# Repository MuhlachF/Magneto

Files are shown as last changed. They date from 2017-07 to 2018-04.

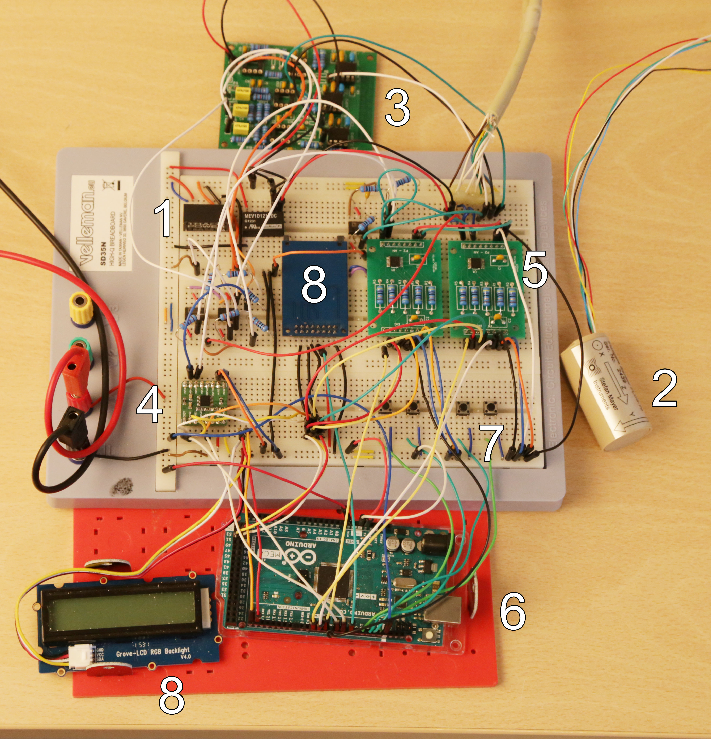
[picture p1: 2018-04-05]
Magnetometre/Prototype.jpg

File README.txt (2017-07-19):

---------------------------------
1. Principe du sondage éléctrique
---------------------------------
La prospection électrique consiste à injecter des courants sur une paire 
d’électrodes plantées dans le sol et à mesurer des potentiels en d’autres 
points de la surface. 

Livre Applied Geophysics 1: Electrical Methods
Auteur principal : Nicolas Florsch / Co-auteur : Frédéric MUHLACH
Relié: 220 pages
Editeur : ISTE Press - Elsevier (20 novembre 2017)
Langue : Anglais
ISBN-10: 1785481991
ISBN-13: 978-1785481994

-----------------------------------
2. Présentation du projet : Magneto
-----------------------------------

Le projet de réalisation qui vous est ici présenté est destiné à la prospection 
électrique du sous-sol par mesure de résistivité. Cet appareil est «opensource» 
et vous pourrez donc modifier à votre guise le programme qu’il contient pour 
l’adapter à vos besoins ou ajouter de nouvelles fonctionnalités. 

Cet appareil est uniquement dédié à l’acquisition de valeurs analogiques, 
telles qu’intensités et tensions. Les signaux sont ensuite convertis au format 
numérique et sauvegardés sur un support de stockage pour y être analysés, à
l’aide d’un logiciel spécialisé de géophysique. Il s’agit de déterminer la 
variation spatiale des résistivités du sous-sol.

-------------------------
3. Architecture du projet
-------------------------
                          |---------------|             |-------------|
                          | Affichage des |             |  Horodatage | 
                          | informations  |             |    + GPS    |
                          |---------------|             |-------------|
                                   ^                            |
                                   |                            V                
    |------------|          |------------|         |------------------------|
    | Conversion |--------->| Traitement |-------->| Sauvegarde des données |
    | Analog/Num |          |    (µc)    |         |       collectées       |
    |------------|          |------------|         |------------------------|
                                   |
                                   v
                            |------------|
                            | Saisie des |
                            | paramètres |
                            |------------|
	
----------------------------------------
4. Présentation des composants matériels
----------------------------------------
4.1 Le microcontrôleur
----------------------------------------
Le microcontrôleur est un circuit intégré (ou IC Integrated Circuit) dont les 
tâches principales sont :
	• Le traitement des informations,
	• Le pilotage des périphériques connectés sur ses broches.

Notre choix s’est porté sur la version Arduino Mega2560, qui dispose de la 
quantité de mémoire suffisante pour faire tourner le programme. 

Remarque : le modèle UNO, reste utilisable, à condition de renoncer à 
l’acquisition des données GPS.

https://www.arduino.cc/en/Main/ArduinoBoardMega2560

-----------------------------------------
4.2 Le convertisseur analogique-numérique
-----------------------------------------
Le convertisseur analogique numérique CAN (ou ADC Analog to Digital Converter) 
est un dispositif électronique qui traduit des signaux analogiques en données 
numériques.

Les entrées des CAN acceptent généralement deux modes de fonctionnement :
	• Single Ended : tension mesurée sur un seul fil, avec pour référence la 
	masse du montage. 
	• Différentiel : tension mesurée entre entre deux fils ; les interférences, 
	présentes sur les deux voies, ne sont donc pas prises en compte.
	
Le convertisseur ADS1115 (16 bits de résolution) est ici utilisé dans sa version
«breakout Board » par la société Adafruit :

https://www.adafruit.com/product/1085

-------------------------
4.3 Le Clavier analogique
-------------------------
périphérique proposé par Sparkfun (VKey PRT12080 )

https://www.sparkfun.com/products/12080

Mapping du clavier :

#############################
#        #         #        #
#   1    # 2 ou ^  #   3    #                 
#        #         #        #
#############################
#        #         #        #
#   4    # 5 ou OK #   6    #
#        #         #        #
#############################
#        #         #        #
#   7    # 8 ou v  #   9    #
#        #         #        #
#############################
# cls .  #         #        #
# ou ret #    0    #  Enter #
#        #         #        #
#############################

---------------------
4.4 Ecran LCD RVB I²C
---------------------
Ecran de 2 lignes de 16 caractères, qui affiche les informations de paramétrage 
et les menus. Un rétroéclairage peut être activé.

http://wiki.seeed.cc/Grove-LCD_RGB_Backlight/

--------------
4.5 Module RTC
--------------
L’horloge RTC (Real Time Clock) indique l'heure à la nanoseconde près. La carte 
proposée au format Grove par la société Seeed ,dont le composant central est un 
circuit DS1307.

http://wiki.seeed.cc/Grove-RTC/

--------------------------------------
4.6 Lecteur de carte µSD au format SPI
--------------------------------------
Support de stockage utilisé pour sauvegarder toutes les données au fil des 
acquisitions.

https://www.adafruit.com/product/254

-------------
5. Connexions
-------------

|------------------------------------------------------------------------------|
|       Périphérique      |   Connexion et alimentation    | Protocole utilisé |
|------------------------------------------------------------------------------|
| Clavier                 | + -> 5 Volts et GND (masse)    | Analogique        |
|                         | Out -> Entrée Arduino A0       |                   |
|------------------------------------------------------------------------------|
| Option (GPS Adafruit)   | Vin (5Volts) et GND (masse)    | Série             |
|                         | TX -> RX1 Arduino              |                   |
|                         | RX -> TX1 Arduino              |                   |
|------------------------------------------------------------------------------|
| Lecteur de carte microSD| + -> 5 Volts et GND (masse)    | SPI               |
| (Adafruit)              | CLK -> port 52 (SCK)           |                   |
|                         | DO -> port 50 (MISO)           |                   |
|                         | DI -> port 51 (MOSI)           |                   |
|                         | CS -> port 53 (SS)             |                   |
|------------------------------------------------------------------------------|
| ADS1115 (Adafruit)      | VDD -> 5 Volts et GND (masse)  |                   |
|                         | SCL -> port 21 (SCL)           | I²C               |
|                         | SDA -> port 20 (SDA)           | (Adr : 0x48)      |
|                         | ADR -> GND                     |                   |
|------------------------------------------------------------------------------|
| Module RTC (Grove) 	  | VDD -> 5 Volts et GND (masse)  | I²C               |
|                         | SCL -> port 21 (SCL)           |                   |
|                         | SDA -> port 20 (SDA)           |                   |
|------------------------------------------------------------------------------|
| Ecran LCD (Grove) 	  | VDD -> 5 Volts et GND (masse)  | I²C               |
|                         | SCL -> port 21 (SCL)           |                   |
|                         | SDA -> port 20 (SDA)           |                   |
|------------------------------------------------------------------------------|

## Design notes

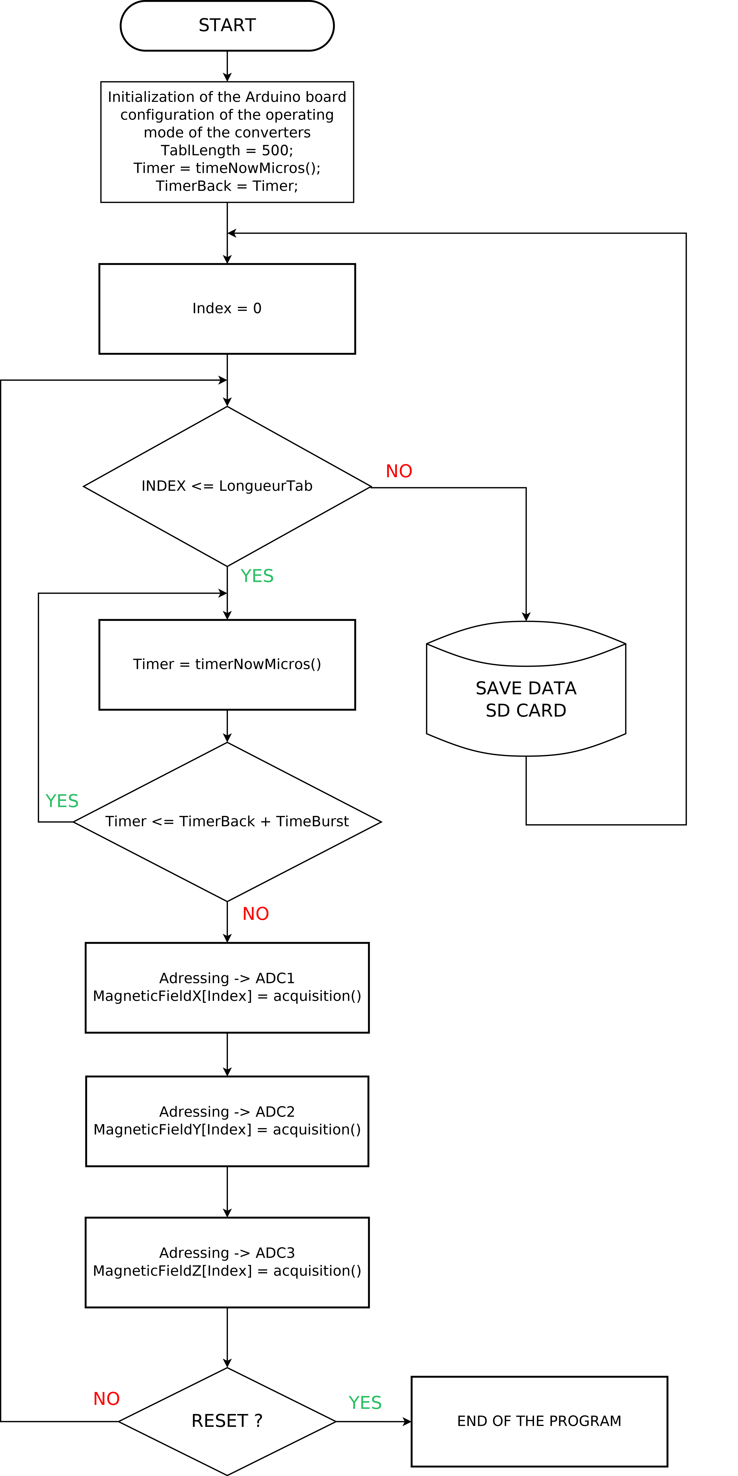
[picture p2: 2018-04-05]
Magnetometre/Principe_Magneto/11_Algo.png

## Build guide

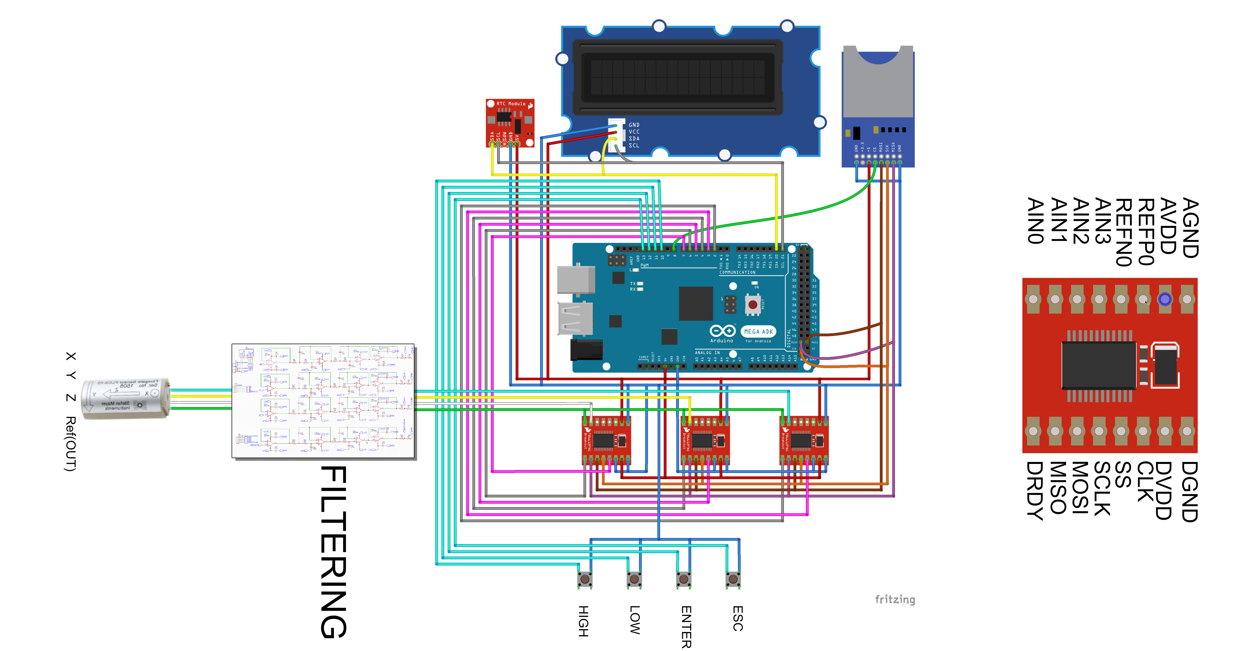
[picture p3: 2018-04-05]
Magnetometre/Assemblage_modules.png

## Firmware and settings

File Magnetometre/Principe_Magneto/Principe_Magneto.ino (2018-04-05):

/*************************************************************
Protocentral_ADS1220.ino
Exemple d'utilisation de la nouvelle librairie
Author : Frédéric MUHLACH
|ads1220 pin label| Pin Function         |Arduino Connection UNO| MEGA |
|-----------------|:--------------------:|---------------------:|:-----
| DRDY            | Data ready Output pin|  D6                  | D6           
| MISO            | Slave Out            |  D12                 | D50
| MOSI            | Slave In             |  D11                 | D51
| SCLK            | Serial Clock         |  D13                 | D52 
| CS              | Chip Select          |  D7                  | D7
| DVDD            | Digital VDD          |  +5V                 |
| DGND            | Digital Gnd          |  Gnd                 |
| AN0-AN3         | Analog Input         |  Analog Input        |
| AVDD            | Analog VDD           |  -                   |
| AGND            | Analog Gnd           |  -                   |
****************************************************************************/
/* Configuration du CAN 
 * Pour les entrées en mode différentiel
 * Commande :  * ADS1220.set_mode(INPUT_SINGLE_ENDED_AIN0);
 * Paramètres : INPUT_DIFF_AIN0_AIN1 
                INPUT_DIFF_AIN0_AIN2
                INPUT_DIFF_AIN0_AIN3
                INPUT_DIFF_AIN1_AIN2
                INPUT_DIFF_AIN1_AIN3
                INPUT_DIFF_AIN2_AIN3
                INPUT_DIFF_AIN1_AIN0
                INPUT_DIFF_AIN3_AIN2

 * Pour les entrées en mode Single Ended
                INPUT_SINGLE_ENDED_AIN0
                INPUT_SINGLE_ENDED_AIN1
                INPUT_SINGLE_ENDED_AIN2
                INPUT_SINGLE_ENDED_AIN3

 * Vitesse de sampling pour le mode NORMAL  : 20, 45, 90, 175, 330, 600 et 1000 SPS
 * Vitesse de sampling pour le mode TURBO   : 40, 90, 180, 350, 660, 1200 et 2000 SPS
 * 
 * Pour la mise en place d'un filtrage numérique (uniquement pour 20SPS)
 * Commande :   ADS1220.set_filter(REJECTION_50_60HZ)
 * Paramètres : NOFILTER
 *              REJECTION_50_60HZ
 *              REJECTION_50HZ
 *              REJECTION_60HZ
 
 * Pour le mode de fonctionnement du convertisseur
 * Commande :   ADS1220.set_operating_mode(NORMAL)
 * Paramètres : NORMAL
 *              DUTY_CYCLE
 *              TURBO

*/

/* Versionning :
 *  0.1 : Intégration de la librairie ADS1220 et tests de fonctionnement
 *  0.2 : Passage sur Arduino MEGA 2560
 *  0.3 : Intégration d'un menu simplifié
 *    1.  Start scan
      2.  Output data
      3.  Set parameters
          a.  Grid size (max 50*50m) ?
          b.  Interval (increment 0.2m avec max interval = 1m)
          c.  SPS (Samples Per Second)
          d.  Sensors (mono composante ou 3D)
          e.  Reject (activation du filtre rejecteur 50 ou 60Hz)
          f.  Space sensors (distance entre les deux capteurs mono composante)
          g.  Save config
          h.  System reset
      4.  Calibrate
 *  0.4 : Prise en compte du mode TURBO 
 *  0.5 : passage à 660SPS par convertisseur pour diminuer les temps de multiplexage entre CAN
 *  0.6 : Ajout du supersampling pour l'acquisition des signaux
 *  0.7 : Prise en compte des erreurs Offset et Gain sur les 3 entrées
 *  0.8 : Ajout du lecteur de carte SD / initialisation    
 *  0.9 : Prise en compte de l'interface de navigation
 *  0.10 : Conversion parallèle avec 2 CAN / synchronisation des CAN 
 *  0.11 : refactoring de code -> Optimisation de la fonction d'acquisition 
 *  0.12 : Vitesse de commutation fixée à 0
 *  0.13 : Ouverture de fichier
 *  0.14 : Mise en place d'un timer pour la synchronisation des conversions
 *  0.15 : intégration d'une reinit synchro SPI dans la librairie
 *  
 */

#include "Protocentral_ADS1220.h"
#include "rgb_lcd.h"
#include <SD.h>

// DESCRIPTEUR DE FICHIER
File myFile;

// IDENTIFIANTS DES CONVERTISSEURS
#define CAN1                  1
#define CAN2                  2
#define CAN3                  3

// CHIP SELECT BUS SPI
#define SDCARD_CS_PIN         8
#define ADS1220_1_CS_PIN      7
#define ADS1220_1_DRDY_PIN    6
#define ADS1220_2_CS_PIN      5
#define ADS1220_2_DRDY_PIN    4
#define ADS1220_3_CS_PIN      3
#define ADS1220_3_DRDY_PIN    2

// VITESSE DE COMMUTATION Bonne valeur -> TIME_BURST 4000, SS=8 -> 22Hz 1200SPS bruit de 3nT
//                                      -> TIME_BURST 6000, SS=1 -> 70Hz 350SPS bruit de 3nT
//                                     -> TIME_BURST 12000, SS=1 -> 55Hz 180SPS bruit de 2nT
//                                     -> TIME BURST 24000, SS=1 -> 40Hz 90SPS bruit de 1nT
//                                     -> TIME BURST 25000, SS=1 ->      
// MARCHE OK TIME_BURST 15000 et 180SPS 4SS environ 25Hz
#define TIME_BURST           50000  //en µs Baisser cette valeur augmente les erreurs de conversion ! 
                                   // La valeur est à adapter avec le nombre de SPS
#define TIME_SYNCHRO         0
#define TIME_SPI             200     // 

// SUPERSAMPLING 
#define SAMPLES               1 // 20 -> 12Hz, 15 -> 16Hz

// TAILLE TABLEAU
#define LENGTH_ACQUISITION    500  // Avec TIME_BURST=2000, SAMPLES=20, LENGTH_ACQUISITION=400 => MAX 10s de SAMPLES sans interruption

// Interface de navigation
#define KEYBOARD_F            150
#define BTN_DOWN              10
#define BTN_UP                11
#define BTN_ENTER             12
#define BTN_ESCAPE            13
#define ITEMS_MENU_PRINCIPAL  4
#define ITEMS_MENU_SECONDAIRE 8

// Capteur Magnetique 3D
#define X_SENSOR 1
#define Y_SENSOR 2
#define Z_SENSOR 3
#define SENSOR_3D_SENS_X 35 
#define SENSOR_3D_OFFSET_X 0      // sensibilité du capteur magnétique 1V = 70µT
//#define SENSOR_3D_OFFSET_X -69.923  // Offset du capteur magnétique (tension positive sur -70 à 70µT) -> 0 à 2V 

#define SENSOR_3D_SENS_Y 35     // sensibilité du capteur magnétique 1V = 70µT
#define SENSOR_3D_OFFSET_Y 0
//#define SENSOR_3D_OFFSET_Y -69.75  // Offset du capteur magnétique (tension positive sur -70 à 70µT) -> 0 à 2V 

#define SENSOR_3D_SENS_Z 35     // sensibilité du capteur magnétique 1V = 70µT
#define SENSOR_3D_OFFSET_Z 0
//#define SENSOR_3D_OFFSET_Z -69.66  // Offset du capteur magnétique (tension positive sur -70 à 70µT) -> 0 à 2V 

#define DIGIT_PRECISION 3    // Précision de l'affichage au nT    


int codeTouche;
long int timer = millis();
long int timerBack = timer;
int navigationMenuPrincipal = 0;


// Déclaration ECRAN LCD
rgb_lcd lcd;
#define colorR 0
#define colorG 0
#define colorB 0

#include <SPI.h>
#define PGA 1                 // Programmable Gain = 1
#define VREF 2.048            // Internal reference of 2.048V
#define VFSR VREF/PGA             
#define FSR (((long int)1<<23)-1)  

// Variables dédiées au convertisseur
volatile byte MSB;
volatile byte data;
volatile byte LSB;
volatile byte *SPI_RX_Buff_Ptr;

String outPutData="";

float magneticField; 
float magneticFieldX; 
float magneticFieldY; 
float magneticFieldZ; 

float magneticFieldBackX; 
float magneticFieldBackY; 
float magneticFieldBackZ; 

float MagneticFieldX = 0.0;
float MagneticFieldY = 0.0;
float MagneticFieldZ = 0.0;
float moyenne;

//long timerTab[LENGTH_ACQUISITION]={NULL};
float magneticFieldXTab[LENGTH_ACQUISITION]={NULL};
float magneticFieldYTab[LENGTH_ACQUISITION]={NULL};
float magneticFieldZTab[LENGTH_ACQUISITION]={NULL};

float sensorOffset = 0.0;
float sensorGain = 0.0;
 
Protocentral_ADS1220 ADS1220;
Protocentral_ADS1220 ADS1220_2;
Protocentral_ADS1220 ADS1220_3;

void setup()
{
  Serial.begin(250000);

  // Paramtrage de l'écran LCD 2 lignes de 16 caractères
  lcd.begin(16, 2);
  lcd.setRGB(colorR, colorG, colorB);
  
  // Initialisation du lecteur de carte SD
  pinMode(SDCARD_CS_PIN, OUTPUT);
  pinMode(SS, OUTPUT);
  activation_SD_CARD();
 
  if (!SD.begin(SDCARD_CS_PIN)) 
  {
    lcd.print("SD Problem"); 
    delay (500);
     
  }
  else
  {
    lcd.print("SD initialized.");
    delay (100);    
  }

  myFile = SD.open("DATA.txt", FILE_WRITE);
  if (myFile)
  {
    myFile.print("LANCEMENT DES ACQUISITIONS");
    myFile.println("");
    myFile.print("-----------------------------");
    myFile.println("");
    myFile.println("");
    
    myFile.close();
  }

  // Configuration interface
  pinMode (BTN_DOWN,INPUT_PULLUP);
  pinMode (BTN_UP,INPUT_PULLUP);
  pinMode (BTN_ENTER,INPUT_PULLUP);
  pinMode (BTN_ESCAPE,INPUT_PULLUP);
  
  // Initialisation des CAN ADS1220
  pinMode(ADS1220_1_CS_PIN, OUTPUT);  
  pinMode(ADS1220_1_DRDY_PIN, INPUT);  
  pinMode(ADS1220_2_CS_PIN, OUTPUT);  
  pinMode(ADS1220_2_DRDY_PIN, INPUT);
  pinMode(ADS1220_3_CS_PIN, OUTPUT);  
  pinMode(ADS1220_3_DRDY_PIN, INPUT);

  

  
  activation_ADS1220_1();
  ADS1220.set_CS_Pin(ADS1220_1_CS_PIN);
  ADS1220.set_DRDY_Pin(ADS1220_1_DRDY_PIN);
  ADS1220.begin();
  delayMicroseconds(TIME_SPI);
  ADS1220.set_mode(INPUT_DIFF_AIN1_AIN2);
  ADS1220.set_operating_mode(TURBO);
  ADS1220.set_data_rate(DR_180SPS);
  ADS1220.Continuous_conversion_mode_ON();
  ADS1220.set_filter(NOFILTER);
  ADS1220.PGA_ON(); 
  ADS1220.set_pga_gain(PGA_GAIN_4);
  delayMicroseconds(TIME_SPI);
  

  activation_ADS1220_2();
  ADS1220_2.set_CS_Pin(ADS1220_2_CS_PIN);
  ADS1220_2.set_DRDY_Pin(ADS1220_2_DRDY_PIN);
  delayMicroseconds(TIME_SPI);
  ADS1220_2.begin();
  ADS1220_2.set_mode(INPUT_DIFF_AIN0_AIN1);
  ADS1220_2.set_operating_mode(TURBO);
  ADS1220_2.set_data_rate(DR_180SPS);
  ADS1220_2.Continuous_conversion_mode_ON();
  ADS1220_2.set_filter(NOFILTER);
  ADS1220_2.PGA_ON(); 
  ADS1220_2.set_pga_gain(PGA_GAIN_4);
  delayMicroseconds(TIME_SPI);

  activation_ADS1220_3();
  ADS1220_3.set_CS_Pin(ADS1220_3_CS_PIN);
  ADS1220_3.set_DRDY_Pin(ADS1220_3_DRDY_PIN);
  delayMicroseconds(TIME_SPI);
  ADS1220_3.begin();
  ADS1220_3.set_mode(INPUT_DIFF_AIN0_AIN2);
  ADS1220_3.set_operating_mode(TURBO);
  ADS1220_3.set_data_rate(DR_180SPS);
  ADS1220_3.Continuous_conversion_mode_ON();
  ADS1220_3.set_filter(NOFILTER);
  ADS1220_3.PGA_ON(); 
  ADS1220_3.set_pga_gain(PGA_GAIN_4);
  delayMicroseconds(TIME_SPI);

  desactivation_SPI();
  affichageMenuPrincipal();     
}
 
void loop()
{
 codeTouche = testTouche();

 switch (codeTouche)
 {
   case BTN_DOWN: 
   navigationMenuPrincipal++;
   navigationMenuPrincipal=constrain(navigationMenuPrincipal,0,ITEMS_MENU_PRINCIPAL-1);
   affichageMenuPrincipal();
   break;

   case BTN_UP:
   navigationMenuPrincipal--;
   navigationMenuPrincipal=constrain(navigationMenuPrincipal,0,ITEMS_MENU_PRINCIPAL-1);
   affichageMenuPrincipal();
   break;

   case BTN_ENTER:

   switch(navigationMenuPrincipal)
   {
      case 0: 
      do
      {
        acquisition();         
      }while (digitalRead(BTN_ESCAPE));
      break;
   }
   
   break;

   case BTN_ESCAPE:
   affichageMenuPrincipal();
   break;

   default:
   break;
 } 

}

void acquisition()
{ 
  

  for (int index=0;index<LENGTH_ACQUISITION;index++)
  {
    MagneticFieldX = 0.0;
    MagneticFieldY = 0.0;
    MagneticFieldZ = 0.0;
    timer = micros();
    timerBack = timer;
    /*
    for (int i=0 ; i<SAMPLES ; i++)
    {
      */
      while (timer < (timerBack + TIME_BURST))
      {
        timer = micros();
      }
      timerBack = timer;
      //delayMicroseconds(TIME_SPI);
      magneticFieldX = Conversion_Analogique_Numerique_ADS1220(X_SENSOR,CAN1);    
      MagneticFieldX = MagneticFieldX + magneticFieldX;
      delayMicroseconds(TIME_SPI);
      
      magneticFieldY = Conversion_Analogique_Numerique_ADS1220(Y_SENSOR,CAN2);
      MagneticFieldY = MagneticFieldY + magneticFieldY;      
      delayMicroseconds(TIME_SPI);
  
      magneticFieldZ = Conversion_Analogique_Numerique_ADS1220(Z_SENSOR,CAN3);
      MagneticFieldZ = MagneticFieldZ + magneticFieldZ;
      delayMicroseconds(TIME_SPI);
/*
    }
    /*
    MagneticFieldX = MagneticFieldX / SAMPLES;
    MagneticFieldY = MagneticFieldY / SAMPLES;
    MagneticFieldZ = MagneticFieldZ / SAMPLES;
    */
    
    
    
    
   magneticField = sqrt(MagneticFieldX*MagneticFieldX+MagneticFieldY*MagneticFieldY+MagneticFieldZ*MagneticFieldZ);
   //timerTab[index] = millis(); 
   Serial.print (millis());
    Serial.print("\t");
    Serial.print(MagneticFieldX,5);
    Serial.print("\t");
    
    Serial.print(MagneticFieldY,5);
    Serial.print("\t");

    Serial.print(MagneticFieldZ,5);
    Serial.print("\t");
    Serial.print(magneticField,5);
    Serial.print("\n");
   magneticFieldXTab[index]=magneticFieldX;
   magneticFieldYTab[index]=magneticFieldY;
   magneticFieldZTab[index]=magneticFieldZ;
     
  AffichageLCD(index);    
  }
  // Activation du lecteur de carte pour enregistrement des mesures
  
  activation_SD_CARD();
  
   myFile = SD.open("DATA.txt", FILE_WRITE);
   if (myFile)
   {
 
      for (int index=0 ; index<LENGTH_ACQUISITION ; index++)
    {
      //myFile.print(timerTab[index]);
      //myFile.print(";");
      myFile.print(magneticFieldXTab[index],6);
      myFile.print(";");
      myFile.print(magneticFieldYTab[index],6);
      myFile.print(";");
      myFile.print(magneticFieldZTab[index],6);
      myFile.println("");
    }
    myFile.close();
    /*
    Serial.print("sauvegarde effectuee");
    Serial.print("\n");  
    */
  }
  
  activation_ADS1220_1();
  ADS1220.SynchroRestart();
  Conversion_Analogique_Numerique_ADS1220(X_SENSOR,CAN1);
  Conversion_Analogique_Numerique_ADS1220(X_SENSOR,CAN2);
  Conversion_Analogique_Numerique_ADS1220(X_SENSOR,CAN3);
  delayMicroseconds(TIME_SYNCHRO);

}
float Conversion_Analogique_Numerique_ADS1220(int Sensor_Canal, int Convertisseur)
{
  // Rappel des configurations / Canal
  switch (Sensor_Canal)
  {
   case X_SENSOR : 
     sensorOffset = SENSOR_3D_OFFSET_X;
     sensorGain = SENSOR_3D_SENS_X;
     break;

   case Y_SENSOR : 
     sensorOffset = SENSOR_3D_OFFSET_Y;
     sensorGain = SENSOR_3D_SENS_Y;
     break;

   case Z_SENSOR : 
     sensorOffset = SENSOR_3D_OFFSET_Z;
     sensorGain = SENSOR_3D_SENS_Z;
     break;
  }
  long int bit32;
  long int bit24;
  byte *config_reg;
  bool lock = false;

  switch (Convertisseur)
  {
    case CAN1 : 
      activation_ADS1220_1();
      SPI_RX_Buff_Ptr = ADS1220.Read_Data();
      SPI_RX_Buff_Ptr = ADS1220.Read_Data();
      if(ADS1220.NewDataAvailable = true)
      {
        ADS1220.NewDataAvailable = false;
        lock = true;
      }
      desactivation_SPI();
      break;

    case CAN2 : 
      activation_ADS1220_2();
      SPI_RX_Buff_Ptr = ADS1220_2.Read_Data();
      SPI_RX_Buff_Ptr = ADS1220_2.Read_Data();
      if(ADS1220_2.NewDataAvailable = true)
      {
        ADS1220_2.NewDataAvailable = false;
        lock = true;
      }
      desactivation_SPI();
      break;

    case CAN3 : 
      activation_ADS1220_3();
      SPI_RX_Buff_Ptr = ADS1220_3.Read_Data();
      SPI_RX_Buff_Ptr = ADS1220_3.Read_Data();
      if(ADS1220_3.NewDataAvailable = true)
      {
        ADS1220_3.NewDataAvailable = false;
        lock = true;
      }
     desactivation_SPI();
      break;
  }
  
  
  if(lock)
  {
  lock = false;
  MSB = SPI_RX_Buff_Ptr[0];    
  data = SPI_RX_Buff_Ptr[1];
  LSB = SPI_RX_Buff_Ptr[2];

  bit24 = MSB;
  bit24 = (bit24 << 8) | data;
  bit24 = (bit24 << 8) | LSB;                   // Converting 3 bytes to a 24 bit int
    
  bit24= ( bit24 << 8 );
  bit32 = ( bit24 >> 8 );                      // Converting 24 bit two's complement to 32 bit two's complement
  
  return (float)(((((bit32*VFSR)/FSR)*sensorGain))+sensorOffset);     //In  µT
  //return (float)((bit32*VFSR*1000)/FSR);     //In  mV
  } 
}


void AffichageLCD(int index)
{
  lcd.clear();
  lcd.print(index);
  lcd.setCursor(2,0);
  lcd.print("MAG1="+String(magneticField,DIGIT_PRECISION)+" "); 
}

void affichageMenuPrincipal()
{
  desactivation_SPI();
  lcd.clear();
  lcd.setCursor(0,0);
  lcd.print ("---MAIN MENU----");
  lcd.setCursor(0,1);
   switch (navigationMenuPrincipal)
 {
    case 0:
    lcd.print("1-> START");
    break;

    case 1:
    lcd.print("2-> OUTPUT DATA");
    break;

    case 2:
    lcd.print("3-> SET PARAM"); 
    break;

    case 3:
    lcd.print("4-> CALIBRATE"); 
    break;
 }
}
/* 
 *  FONCTION TEST TOUCHE
 *  RENVOI LA VALEUR DE LA TOUCHE APPUYEE
 *  AUCUN PARAMETRE
 */
int testTouche()
{  
  timer = millis();
  if ((timer - timerBack) > KEYBOARD_F)
  {   
      if (!digitalRead(BTN_DOWN))
      { 
        timerBack = timer;
        return BTN_DOWN;
      }

      if (!digitalRead(BTN_UP))
      { 
        timerBack = timer;
        return BTN_UP;
      }
      
      if (!digitalRead(BTN_ENTER))
      { 
        timerBack = timer;
        return BTN_ENTER;
      }

      if (!digitalRead(BTN_ESCAPE))
      { 
        timerBack = timer;
        return BTN_ESCAPE;
      }    
      timerBack=timer;
      
  }
    return 0;  
}

void activation_SD_CARD()
{
  digitalWrite(ADS1220_1_CS_PIN,HIGH);
  digitalWrite(ADS1220_2_CS_PIN,HIGH);
  digitalWrite(ADS1220_3_CS_PIN,HIGH);
  delayMicroseconds(TIME_SPI);
  digitalWrite(SDCARD_CS_PIN,LOW); 
  delayMicroseconds(TIME_SPI);
}

void activation_ADS1220_1()
{
  digitalWrite(SDCARD_CS_PIN,HIGH);
  digitalWrite(ADS1220_2_CS_PIN,HIGH); 
  digitalWrite(ADS1220_3_CS_PIN,HIGH); 
  delayMicroseconds(TIME_SPI);
  digitalWrite(ADS1220_1_CS_PIN,LOW);
  delayMicroseconds(TIME_SPI);
}

void activation_ADS1220_2()
{
  digitalWrite(SDCARD_CS_PIN,HIGH);
  digitalWrite(ADS1220_1_CS_PIN,HIGH); 
  digitalWrite(ADS1220_3_CS_PIN,HIGH); 
  delayMicroseconds(TIME_SPI);
  digitalWrite(ADS1220_2_CS_PIN,LOW);
  delayMicroseconds(TIME_SPI);
}

void activation_ADS1220_3()
{
  digitalWrite(SDCARD_CS_PIN,HIGH);
  digitalWrite(ADS1220_1_CS_PIN,HIGH); 
  digitalWrite(ADS1220_2_CS_PIN,HIGH); 
  delayMicroseconds(TIME_SPI);
  digitalWrite(ADS1220_3_CS_PIN,LOW);
  delayMicroseconds(TIME_SPI);
}

void desactivation_SPI()
{
  digitalWrite(SDCARD_CS_PIN,HIGH);
  digitalWrite(ADS1220_1_CS_PIN,HIGH); 
  digitalWrite(ADS1220_2_CS_PIN,HIGH); 
  digitalWrite(ADS1220_3_CS_PIN,HIGH); 
  delayMicroseconds(TIME_SPI);
}
/* 
 *  FIN FONCTION TEST TOUCHE
 */


 
 

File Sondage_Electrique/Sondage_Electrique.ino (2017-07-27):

/*
  Centrale d'acquisition des mesures / magnétomètre
  

  Author : Frédéric MUHLACH
  2017-05-10

  Magneto-mesure

  VERSIONS DU PROGRAMME

  Version : 0.1  (2017/05/10) -> Prise en compte du clavier analogique
  Version : 0.2  (2017/05/11) -> Intégration et navigation dans les menus
  Version : 0.3  (2017/05/12) -> Ajout du module de paramétrage des mesures
  Version : 0.4  (2017/05/17) -> Configuration des modes de mesures
  Version : 0.5  (2017/05/30) -> Intégration du CAN
                DEBUG : NOM DE L'IDENTIFIANT LIMITE A 6 CARACTERES
  Version : 0.6  (2017/05/31) -> Ajout menu configuration spécifique
                Schlumberger ou Wenner
  Version : 0.7  (2017/05/31) -> Debug Timer clavier
  Version : 0.8  (2017/05/31) -> Debug BLOCAGE MENU PRINCIPAL
  Version : 0.9  (2017/06/01) -> Mesures spécifiques suivant Schlumberger
  Version : 0.10 (2017/06/01) -> Warning si nbMesures non défini
  Version : 0.11 (2017/06/01) -> Initialisation du support de stockage / carte SD
                              -> Augmentation de la luminosité / affichage extérieur
  Version : 0.12 (2017/06/02) -> Ajout fonction lectureValeurFloat() permettant la saisie de nombres décimaux
  Version : 0.13 (2017/06/03) -> Optimisation du code + Ajout fonction SuperFloatString
                              -> passage de précision 32 à 64 bits
  Version : 0.14 (2017/06/03) -> Optimisation fonction et ajout constante de précision LCD et FICHIER
                              -> Version buggée sur SuperString et coeff
  Version : 0.15 (2017/06/06) -> La precision des floats est données par String(CHAINE,PRECISION)
                              -> ATTENTION PRECISION DES CALCULS EN MODE FLOAT (ARDUINO UNO ET MEGA FLOAT CODE SUR 4 OCTETS !!!)
                              -> Intégration des mesures spécifiques suivant Wenner
  Version : 0.16 (2017/06/08) -> Optimisation du calcul des constantes / balayage des tableaux
                              -> simplificiation des menus 
  Version : 0.17 (2017/06/08) -> Ajout du sous-menu / paramétrage dipole-dipole
  Version : 0.18 (2017/06/08) -> Configuration des parametres dipole-dipole

  Version : 0.17 (2017/06/09) -> ajout du Menu I
                              -> réorganisation des fonctions / modification de la portée de certaines variables
                              -> Suppression d'un maximum de delay() pouvant être la source de nombreux problèmes
                              -> ajout du paramétrage des capteurs magnétiques
                              -> suppression du type float au profit du double (précision de 64 bits sur Arduino Due)

  Version : 0.18 (2017/06/09) -> Acquisition des données suivant profil pour les sondages electriques Dipôle-Dipôle et magnétiques
                              -> Ajout des commentaires
                              -> Debug confspecifique
                              -> Ajout de données / flux de sortie 

  Version : 0.19 (2017/06/13) -> Correction d'un Bug -> initialisation carte SD (Alimentation USB)
                              -> Correction du formatage pour le flux de sortie Schlumberger
                              -> Passage en gain de 2 pour des tensions d'entrée de -2.048 à 2.048V
                              -> Vérification des mesures
                              -> Attention en cas de recharge de carte SD faire un reset sur la carte pour prise en compte
  Version : 0.20 (2017/06/14) -> Fonction acquisition Dipole-Dipole    
  Version : 0.21 (2017/06/14) -> Fonction acquisition Dipole-Dipole  
  Version : 0.22 (2017/06/14) -> Ajout du sous-menu positionnement
  Version : 0.23 (2017/06/15) -> Modification menu Freq-Walking(Hz)
                              -> Correction d'un bug / débordement menu mesureI
                              -> Valeurs décimales sur 4 digits 
                              -> Remplacement des valeurs MN et AB (schlumberger) par OM et OA
                              -> Remplacement de Resistance du Shunt par Facteur de Conversion
                              -> Suppression du menu nombre de mesures -> possibilité de quitter le programme en cours
                              -> modification du menu
                              
                              1) Configuration
                                  0-Identifiant      // identifiant de fichier valeur numérique de 0 à 999999
                                  1-Mode             // selection d'un mode pour l'acquisition des mesures (mesures specifiques, selon profil ou carte)
                                  2-Mesures de I     // I est mesurée ou un coefficient est renseigné
                                  3-Frequence(Bst)   // Fréquence utilisée pour les sondages suivants profils ou cartes
                                  4-COnf Dip-Dip     // Configuration des electrodes pour les mesures dipole-dipole
                                  5-Dist capteurs    // Distance en cm entre les capteurs
                                  6-Conf profil      // configuration du profil : distance/X et pas/X
                                  7-Conf carte       // configuration de la carte : distance/X et /Y et pas/X et/Y
                                  8-Positionnement   // Choix pour l'utilisateur -> Aucun, position manuelle, GPS
                                  9-Synchro GPS      // Renseigne sur l'état de synchronisation avec les GPS
                                  10-Freq Keyboard   // Vitesse du clavier
                                  11-LCD-retro       // Configuration des valeurs du retro-éclairage de l'écran LCD
                                  12-Reglage Heure   // Réglage de l'heure
                                  13-Save config     // Permet de sauvegardes la configuration courante
                                  14-Load config     // Lecture du fichier de configuration sur la carte
                                  15-Reset config    // Réinitialise les données et le fichier de configuration
                                  
                              2) Start               // Lancement du processus d'acquisition en fonction de la configuration sélectionnée
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

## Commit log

2017-07-18 refactoring de codes sur la fonction acquisition
2017-07-18 Affichage des conversions en temps réel
2017-07-19 Ajout du document Magento.fzz relatif au schéma Fritzing d'implantation des composants
    [Magneto.fzz]
2017-07-19 Correction de quelques bugs mineurs
    [Sondage_Electrique.ino]
2017-07-19 Définition d'une nouvelle unité pour les mesures : cm
2017-07-19 refactoring de codes et optmisation mémoire / flux création des entetes
2017-07-20 Ajout de la fonctionnalité / inversion pour les mesures suivant profil et carte
2017-07-26 Intégration de la puce RTC et ainsi que dans le flux de sauvegarde
2017-07-26 Amélioration du flux de sauvegarde de l'étiquette
2017-07-26 Ajout de la fonctionnalité mesures suivant profil
2017-07-26 Refactoring de codes / gestion des mesures
2017-07-26 Refactoring de codes / fonction mesures()
2017-07-27 Version de production 1.0
2018-04-05 Ajout de la librairie ADS1220 + principe d'acquisition avec le magneto
2018-04-05 Ajout librairie ADS1220 + programme / principe de mesure magnetometre
2018-04-05 Principe de prospection magnétique des sols / conception appareil
